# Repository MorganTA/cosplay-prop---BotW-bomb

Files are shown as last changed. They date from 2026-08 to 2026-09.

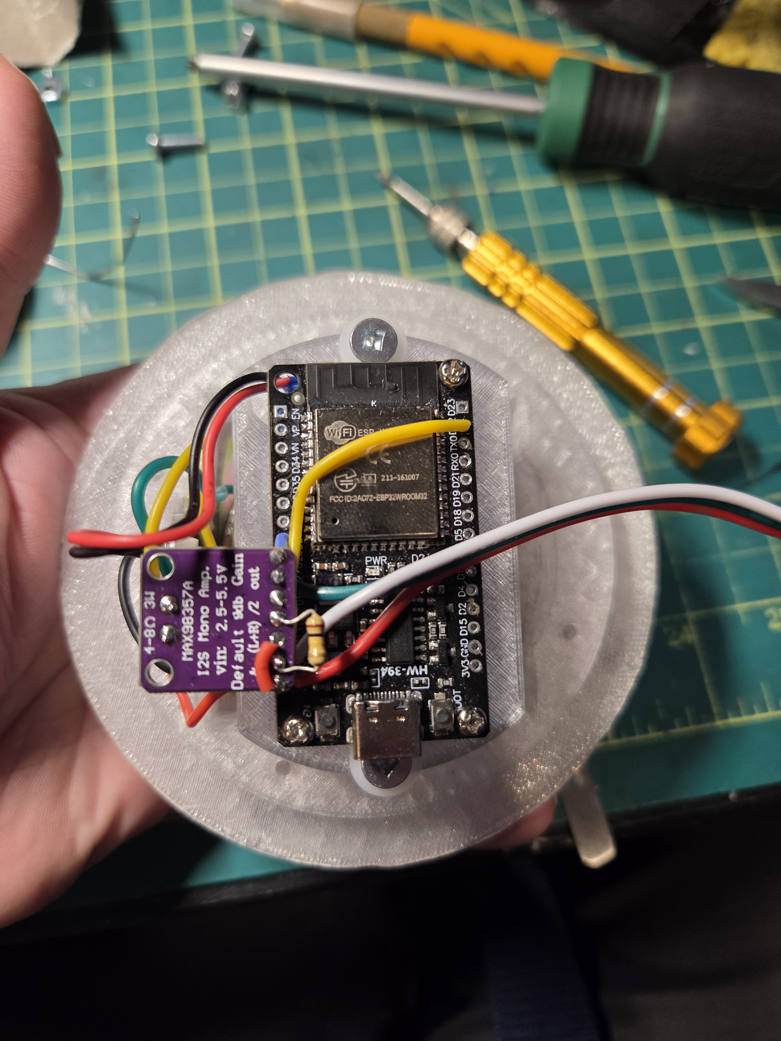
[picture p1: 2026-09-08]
Assembly Pictures/BoTW Remote Bomb Assembly (9).jpg

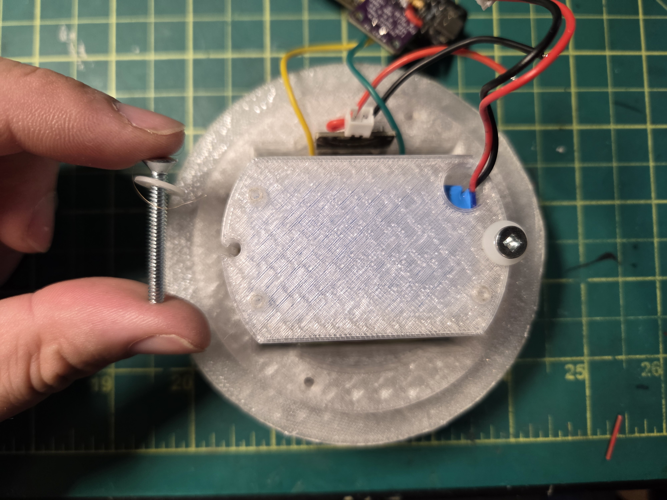
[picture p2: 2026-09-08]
Assembly Pictures/BoTW Remote Bomb Assembly (5).jpg

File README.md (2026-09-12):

# Zelda: Breath of the Wild — Remote Bomb Prop
https://www.instagram.com/reel/DdAoqvsIL6p/?stkn=bnQzZnl1bjlta2x1

Here is the codes for my Breath of the Wild Remote Bomb prop. I have a phone in my Sheikah slate, so I wanted to connect the bomb with Bluetooth to control it.
I had to upload the HTML file to make the APK, so I might as well share it here for anyone who wants to try and make one.

The project was coded with Claude AI, so feel free to modify it as you want. You might want to change the LED count, its currently set for 36 from when I was doing the initial tests.
I also used it for most of this documentation because I am not going to be putting a lot of effort into this.

---
## 3D Model

This is the original model I used.
https://www.thingiverse.com/thing:4860007

I modified it fit a 6-inch Mr.Go LED ball. I'm not vert good with modeling, I used 3D builder to modify the model. Hopefully you wont have much trouble using them. I'll add my WIP file if it helps anyone with editing, please not that it's not that great, and some parts might not fit as the finished ones do.

---

## Features

- Bluetooth Low Energy control via a web app (no app install required on Android)
- Blue breathing LED glow when armed
- Red fade-to-off LED explosion effect on detonation
- I2S audio playback through a MAX98357A amplifier
- Volume slider in the control app
- Works fully offline after first load (PWA with service worker caching)
- Can be installed as a standalone Android app (no address bar) via PWABuilder

---

## Hardware

| Part | Notes | Link |
|---|---|---|
| Mr.Go 6-inch RGB Color-Changing LED Ball Light | I used this for the main body | https://www.amazon.ca/dp/B01HXXUZFG?ref=ppx_yo2ov_dt_b_fed_asin_title&th=1 |
| ESP-WROOM-32 dev board | Any standard ESP32 Dev Module works |
| MAX98357A I2S amp | Digital amp + DAC in one chip, no separate DAC needed | https://www.aliexpress.com/item/1005008274847319.html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 |
| Speaker | 4Ω or 8Ω, 3W | I had mine laying around. Its about 53mmx53mmx24mm |
| WS2812B addressable LEDs | Strip or ring, 36 LEDs | |
| LiPo battery | 3.7V | I just took the one from the Mr.Go light |
| Battery Charging & Boost Converter | I had some of these left over and it saves on space not needing two boards | https://www.aliexpress.com/item/1005005108273423.html?spm=a2g0o.order_list.order_list_main.82.6e0f1802KXwK5v |
| SPDT 1P2T toggle switch | 8.5mm x 3.5mm handle 3mm | https://www.aliexpress.com/item/1005010111050912.html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 |
| 100kΩ resistor | for the MAX98357A audio chip to increase volume | |
| 330Ω resistor | In series on the WS2812B data line |  |
| 470–1000µF capacitor | Across the 5V/GND rail near the LED strip |  |

---

## Wiring

### MAX98357A → ESP32

| MAX98357A | ESP32 |
|---|---|
| VIN | 5V |
| GND | GND |
| BCLK | GPIO26 |
| LRC (WS) | GPIO25 |
| DIN | GPIO22 |
| GAIN | GND (12dB), or 100kΩ resistor to GND (15dB max) |
| SD | VIN (always enabled) |

Connect the speaker's two leads to the MAX98357A's `+` and `−` output terminals.

### WS2812B LEDs → ESP32

| LED | ESP32 |
|---|---|
| VCC | 5V |
| GND | GND |
| DIN | GPIO27 (through a 330Ω resistor) |

### Power rail

```
LiPo (+) → TP4056 IN+ → TP4056 OUT+ → Boost converter IN+
→ Boost converter OUT+ (5V) → [SWITCH] → ESP32 5V / MAX98357A VIN / LED VCC
```

All GND connections share a common rail. Place a 470–1000µF capacitor across 5V/GND near the LED strip to prevent brownouts during bright flashes.

> **Tip:** Wire the switch after the boost converter, not before the TP4056. This way the battery charges normally via USB even when the prop is switched off.

---

## Firmware

### Prerequisites

- [Arduino IDE 2.x](https://www.arduino.cc/en/software)
- ESP32 board package by Espressif Systems **3.0 or later** (add `https://raw.githubusercontent.com/espressif/arduino-esp32/gh-pages/package_esp32_index.json` to Additional Board Manager URLs)
- [arduino-littlefs-upload](https://github.com/earlephilhower/arduino-littlefs-upload) plugin for Arduino IDE 2.x

### Libraries (install via Library Manager)

- **NimBLE-Arduino** by h2zero
- **Adafruit NeoPixel** by Adafruit

> The I2S driver and LittleFS are both bundled with the ESP32 board package — no extra install needed.

### Board settings

| Setting | Value |
|---|---|
| Board | ESP32 Dev Module |
| Partition Scheme | Huge APP (3MB No OTA/1MB SPIFFS) |
| PSRAM | Disabled |

### Audio files

Prepare two files:
- `Bomb_appear01.wav` — played when the bomb is armed
- `RemoteBomb.wav` — played on detonation (~2 seconds)

Both must be **16-bit PCM WAV** format. Mono or stereo both work. 22050 Hz or 44100 Hz sample rate recommended. You can convert and export in this format using [Audacity](https://www.audacityteam.org/) (File > Export > Export as WAV > Encoding: 16-bit PCM).

Place both files in a folder named `data` inside the sketch folder:

```
botw_bomb_firmware/
├── botw_bomb_firmware.ino
└── data/
    ├── Bomb_appear01.wav
    └── RemoteBomb.wav
```

### Flashing

**Step 1 — Upload the audio files (do this first)**

1. Close the Serial Monitor if it's open (the port must be free)
2. Select the correct board and COM port under Tools
3. Open the Command Palette (`Ctrl+Shift+P` / `Cmd+Shift+P`) and run **Upload LittleFS to Pico/ESP32**
4. Wait for it to finish before continuing

**Step 2 — Upload the sketch**

1. Click the **Upload** button as normal
2. Open Serial Monitor at **115200 baud**
3. Confirm you see: `Advertising as 'BotW Bomb' — open the web app and tap Connect.`

> If you change the partition scheme at any point, re-upload the LittleFS filesystem too — changing the partition layout moves where the filesystem lives in flash.

---

## Control App

The web app (`bomb_detonator.html`) is a Progressive Web App that runs in Chrome on Android. It communicates with the ESP32 over Web Bluetooth.

You can run the detonator program right from your web browser (Chrome is recommended) or you can download the apk from this repository. (the apk just loads the site)
https://morganta.github.io/cosplay-prop---BotW-bomb/bomb_detonator.html

If you want to host it yourself follow the info down below. If your just running it as is you don't need to worry, but if you want to make changes of your own you'll need to do it.

### Hosting

Web Bluetooth requires a secure origin (HTTPS or localhost). Host the app files on any free static host:

- [GitHub Pages](https://pages.github.com) (free, recommended)
- [Netlify Drop](https://app.netlify.com/drop) (no account needed, drag and drop)

Upload all five files together:

```
bomb_detonator.html
manifest.json
sw.js
icon-192.png
icon-512.png
```

### Offline use

The service worker (`sw.js`) caches everything after the first successful load over a network connection. Once cached, the app works fully offline. Open it once while connected to WiFi to prime the cache.

> Whenever you update the app files, bump the `CACHE_NAME` version string in `sw.js` (e.g. `v4` → `v5`) so the service worker fetches and re-caches the updated files next time it's online.

### Installing as a standalone Android app (no address bar)

Use [PWABuilder](https://www.pwabuilder.com) to generate a signed APK:

1. Enter your hosted HTTPS URL and click **Start**
2. Choose **Android** as the package type
3. Set your app name and choose **Create new** for the signing key — save the keystore file and credentials somewhere safe
4. Download the generated ZIP and copy the `.apk` file to your phone via USB
5. Upload the included `assetlinks.json` to your hosted site at `/.well-known/assetlinks.json` — this proves domain ownership so the app can go truly fullscreen
6. Install the APK on your phone (Settings > Apps > allow installs from your file manager if prompted)
7. Open the app once while online to let the service worker cache everything

### Usage

1. Open the app and tap **Connect Bomb** — select **BotW Bomb** from the device picker
2. Tap the bomb icon once to arm (blue glow + appear sound)
3. Tap again to detonate (red flash + explosion sound)
4. Use the volume slider to adjust playback volume

---

## Customisation

| Thing to change | Where |
|---|---|
| Number of LEDs | `#define NUM_LEDS` in the firmware |
| LED data pin | `#define LED_PIN` in the firmware |
| I2S pins | `#define I2S_BCLK / I2S_LRC / I2S_DOUT` in the firmware |
| Explosion duration | `#define BOOM_MIN_DURATION_MS` in the firmware |
| Audio filenames | `playWav()` calls in `handleTrigger()` |
| BLE device name | `NimBLEDevice::init()` and `scanResponseData.setName()` in setup |

---

## Troubleshooting

| Problem | Fix |
|---|---|
| `Could not open COM port` | Close the Serial Monitor before uploading |
| `Sketch too big` | Set Partition Scheme to **Huge APP (3MB No OTA/1MB SPIFFS)** |
| `OOM: failed to allocate AudioBuffer` | Make sure PSRAM is set to **Disabled** in board settings |
| `override` compile errors | Update the ESP32 board package to 3.x |
| No audio, no error | Check SD pin is wired to VIN on the MAX98357A; verify BCLK/LRC/DIN wiring |
| BLE shows as Unknown Device | Re-flash after confirming `scanResponseData.setName()` is in setup |
| App icon not going red | Hard-refresh Chrome after updating the hosted files |
| APK won't install | Try transferring via USB cable; check for a Play Protect warning to dismiss |
| App needs internet to launch | Open it once while on WiFi to let the service worker cache everything |

---

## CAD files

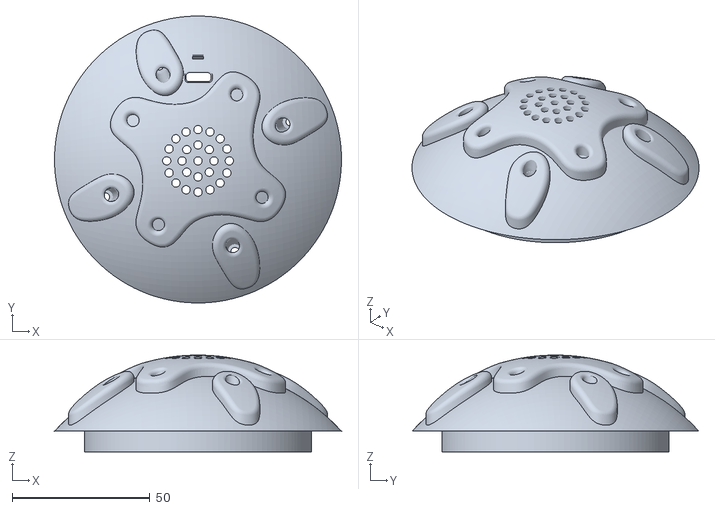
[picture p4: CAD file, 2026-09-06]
3D Model/RemoteBomb_Bottom.stl
104.1 x 104.0 x 35.1

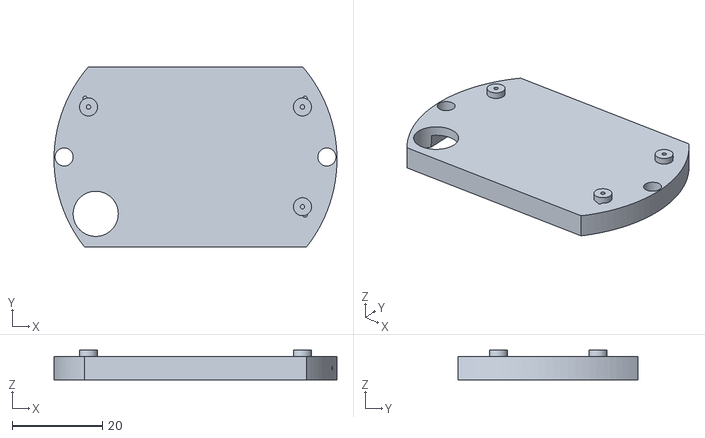
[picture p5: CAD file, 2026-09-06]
3D Model/ESP holder.stl
62.8 x 40.0 x 6.57

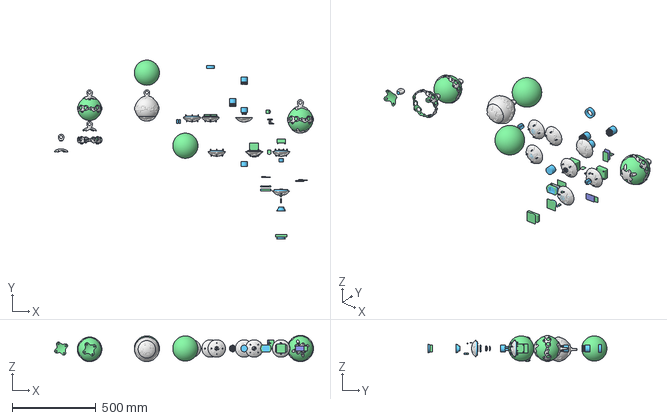
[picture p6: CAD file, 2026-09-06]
3D Model/Remote bomb WIP.3mf
1542.9 x 1065.4 x 156.0 mm

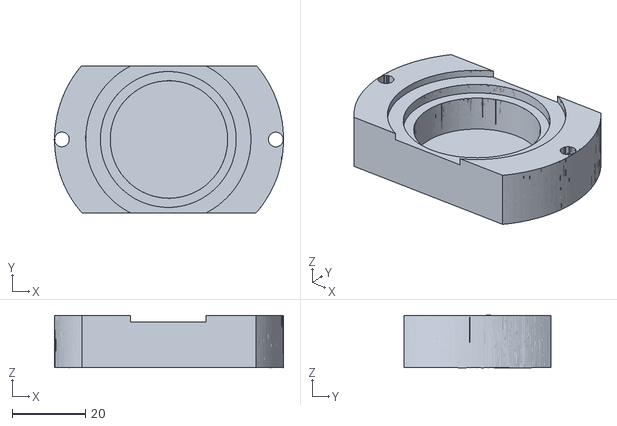
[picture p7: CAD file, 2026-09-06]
3D Model/Battery_holder.stl
62.4 x 40.0 x 14.3

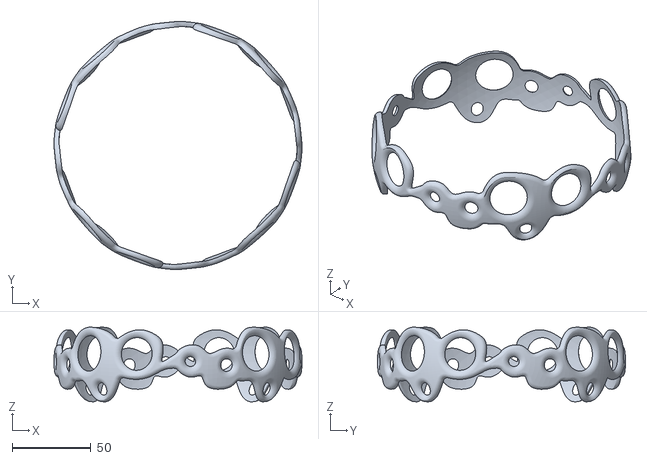
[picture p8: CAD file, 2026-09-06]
3D Model/RemoteBomb_Outer_Rings.stl
157.0 x 157.0 x 47.3

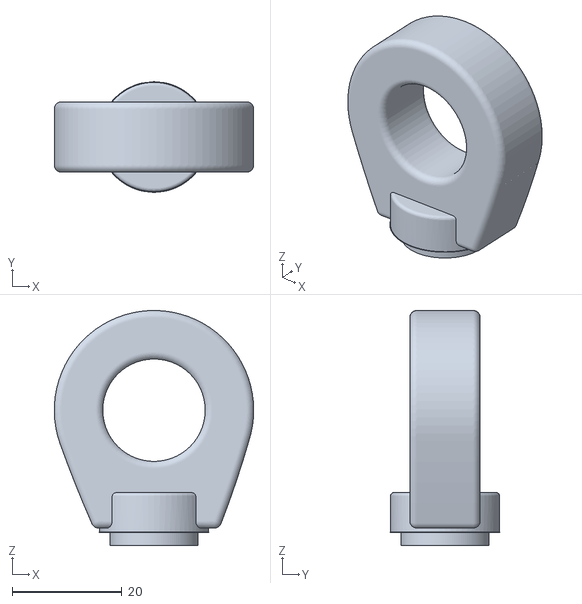
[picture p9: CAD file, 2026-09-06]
3D Model/RemoteBomb_Top_handel.stl
36.3 x 20.1 x 42.7

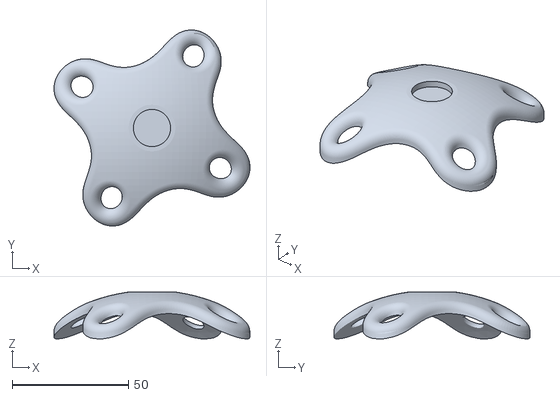
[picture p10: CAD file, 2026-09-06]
3D Model/RemoteBomb_Top.stl
84.4 x 84.4 x 20.2

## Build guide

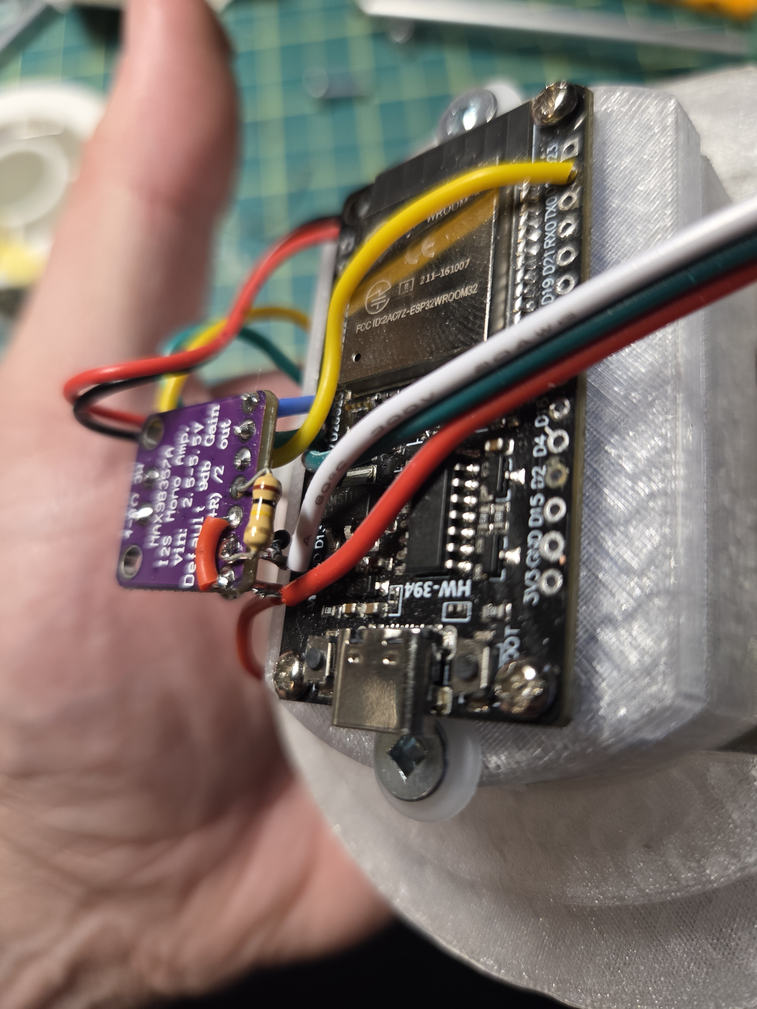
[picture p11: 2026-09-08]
Assembly Pictures/BoTW Remote Bomb Assembly (8).jpg

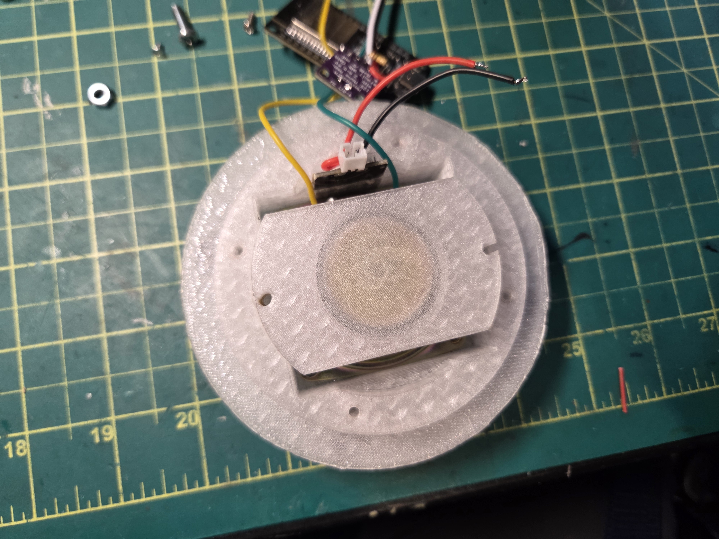
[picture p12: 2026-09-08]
Assembly Pictures/BoTW Remote Bomb Assembly (4).jpg

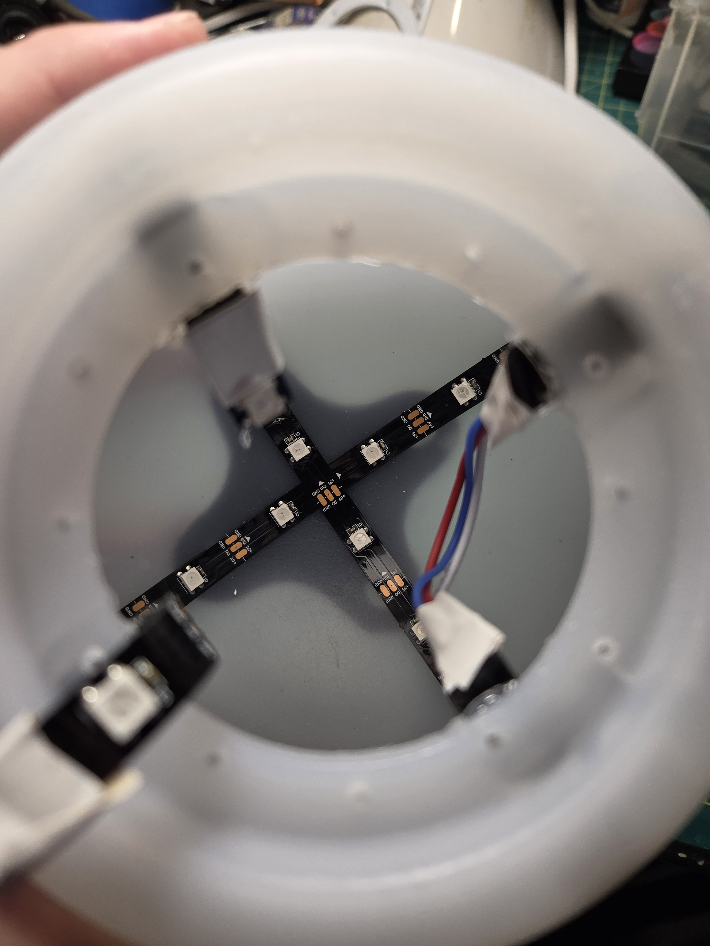
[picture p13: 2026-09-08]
Assembly Pictures/BoTW Remote Bomb Assembly (10).jpg

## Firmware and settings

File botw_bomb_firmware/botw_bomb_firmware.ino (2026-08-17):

/*
 * Zelda BotW Remote Bomb Prop — ESP32 firmware
 * ESP-WROOM-32 + MAX98357A (I2S amp) + WS2812B LEDs, controlled over BLE
 *
 * Behavior:
 *   Idle          -> LEDs fully off, no sound
 *   1st trigger   -> plays "Bomb_appear01.wav", LEDs soft breathing blue glow
 *   2nd trigger   -> plays "RemoteBomb.wav" (~2s), LEDs flash red for at least
 *                    that long, then LEDs go back off and it's ready to arm again
 *
 * This version plays WAV files directly through the ESP32's built-in I2S
 * driver instead of using the ESP32-audioI2S library. That library is built
 * for streaming/decoding (mp3, internet radio, etc.) and its buffer sizes
 * assume a board with PSRAM; on a plain non-PSRAM ESP-WROOM-32 it can fail
 * to allocate its audio buffer. Since we only need to play two short local
 * WAV clips, a small hand-rolled player avoids that dependency completely
 * and uses only a couple KB of RAM.
 *
 * Libraries required (install via Arduino Library Manager):
 *   - NimBLE-Arduino          by h2zero
 *   - Adafruit NeoPixel       by Adafruit
 *   (LittleFS and the I2S driver both come bundled with the ESP32 board package)
 *
 * Audio files:
 *   Put your own "Bomb_appear01.wav" and "RemoteBomb.wav" (16-bit PCM WAV,
 *   mono or stereo, any standard sample rate) in this sketch's /data folder,
 *   then upload with the LittleFS/SPIFFS uploader tool.
 *
 * Board settings: any standard ESP32 dev module board definition works.
 */

#include <NimBLEDevice.h>
#include <Adafruit_NeoPixel.h>
#include <LittleFS.h>
#include <driver/i2s.h>

// Defined up here (before any function that uses it) so Arduino's
// auto-generated function prototypes - which it inserts near the top of the
// file - can see this type instead of erroring on an unknown type.
struct WavInfo {
  uint32_t sampleRate = 44100;
  uint16_t bitsPerSample = 16;
  uint16_t numChannels = 1;
  uint32_t dataSize = 0;
};

// ---------- Pin map ----------
#define LED_PIN      27
#define NUM_LEDS     36

#define I2S_BCLK     26
#define I2S_LRC      25
#define I2S_DOUT     22
#define I2S_PORT     I2S_NUM_0

// ---------- BLE UUIDs (must match the web app) ----------
#define SERVICE_UUID        "4fafc201-1fb5-459e-8fcc-c5c9c331914b"
#define CHARACTERISTIC_UUID "beb5483e-36e1-4688-b7f5-ea07361b26a8"

// Minimum time (ms) the red flash stays active, so it always covers the
// ~2 second explosion clip even if the file is a little shorter/longer.
#define BOOM_MIN_DURATION_MS 2200

Adafruit_NeoPixel strip(NUM_LEDS, LED_PIN, NEO_GRB + NEO_KHZ800);

NimBLEServer* pServer = nullptr;
NimBLECharacteristic* pChar = nullptr;
bool deviceConnected = false;

enum BombState { IDLE, ARMED, BOOM };
BombState state = IDLE;
unsigned long stateStart = 0;

volatile float g_volume = 0.8f; // 0.0-1.0, controlled by the app's slider

// Forward declarations (needed because these are called from classes defined
// below, before Arduino's auto-prototype generator has a chance to see them)
void notifyState(const char* s);
void handleTrigger();

// ---------- BLE callbacks ----------
class ServerCallbacks : public NimBLEServerCallbacks {
  void onConnect(NimBLEServer* s, NimBLEConnInfo& connInfo) override {
    deviceConnected = true;
    Serial.println("Phone connected");
  }
  void onDisconnect(NimBLEServer* s, NimBLEConnInfo& connInfo, int reason) override {
    deviceConnected = false;
    Serial.println("Phone disconnected, re-advertising");
    NimBLEDevice::startAdvertising();
  }
};

class TriggerCallback : public NimBLECharacteristicCallbacks {
  void onWrite(NimBLECharacteristic* c, NimBLEConnInfo& connInfo) override {
    std::string v = std::string(c->getValue().c_str());
    if (v.empty()) return;

    if (v[0] == 'T') {
      handleTrigger();
    } else if (v[0] == 'V' && v.size() >= 3 && v[1] == ':') {
      // Volume command, format "V:<0-100>" (percent)
      int pct = atoi(v.substr(2).c_str());
      pct = constrain(pct, 0, 100);
      g_volume = pct / 100.0f;
      Serial.printf("Volume set to %d%%\n", pct);
    }
  }
};

void notifyState(const char* s) {
  if (pChar && deviceConnected) {
    pChar->setValue(s);
    pChar->notify();
  }
}

// ---------- LED effects ----------
void setAll(uint32_t c) {
  for (int i = 0; i < NUM_LEDS; i++) strip.setPixelColor(i, c);
  strip.show();
}

void idleEffect() {
  setAll(strip.Color(0, 0, 0)); // fully off
}

void armedEffect() {
  // gentle, constant breathing blue glow
  const float periodMs = 1800.0;
  float phase = fmod((float)millis(), periodMs) / periodMs;
  float b = (sin(phase * 2 * PI) + 1) / 2.0; // 0..1
  int brightness = 20 + (int)(b * 180);      // 20..200
  setAll(strip.Color(0, brightness / 3, brightness)); // soft cyan-blue
}

void boomEffect() {
  unsigned long elapsed = millis() - stateStart;

  if (elapsed < BOOM_MIN_DURATION_MS) {
    // bright red immediately, then eases down to off over the rest of the duration
    float t = (float)elapsed / (float)BOOM_MIN_DURATION_MS; // 0..1
    float decay = 1.0f - (t * t);                           // eased falloff, stays brighter longer up front
    int brightness = (int)(255 * decay);
    if (brightness < 0) brightness = 0;
    setAll(strip.Color(brightness, 0, 0));
  } else {
    setAll(strip.Color(0, 0, 0));
  }
}

// ---------- WAV playback (built-in I2S driver, no external audio library) ----------
bool parseWav(File &f, WavInfo &info) {
  f.seek(0);
  char tag[4];
  uint32_t skip32;

  if (f.read((uint8_t*)tag, 4) != 4 || memcmp(tag, "RIFF", 4) != 0) return false;
  f.read((uint8_t*)&skip32, 4); // RIFF chunk size, unused
  if (f.read((uint8_t*)tag, 4) != 4 || memcmp(tag, "WAVE", 4) != 0) return false;

  while (f.available()) {
    char id[4];
    uint32_t size;
    if (f.read((uint8_t*)id, 4) != 4) break;
    if (f.read((uint8_t*)&size, 4) != 4) break;

    if (memcmp(id, "fmt ", 4) == 0) {
      uint16_t audioFormat, numChannels, blockAlign, bitsPerSample;
      uint32_t sampleRate, byteRate;
      f.read((uint8_t*)&audioFormat, 2);
      f.read((uint8_t*)&numChannels, 2);
      f.read((uint8_t*)&sampleRate, 4);
      f.read((uint8_t*)&byteRate, 4);
      f.read((uint8_t*)&blockAlign, 2);
      f.read((uint8_t*)&bitsPerSample, 2);
      info.numChannels = numChannels;
      info.sampleRate = sampleRate;
      info.bitsPerSample = bitsPerSample;
      if (size > 16) f.seek(size - 16, SeekCur); // skip any extra fmt bytes
    } else if (memcmp(id, "data", 4) == 0) {
      info.dataSize = size;
      return true; // data chunk found and file cursor is positioned right after its header
    } else {
      f.seek(size, SeekCur); // skip chunk we don't care about (e.g. LIST, INFO)
    }
    if (size % 2 == 1) f.seek(1, SeekCur); // chunks are word-aligned
  }
  return false;
}

static uint8_t s_readBuf[1024];
static uint8_t s_writeBuf[2048];

bool playWav(const char* path) {
  File f = LittleFS.open(path, "r");
  if (!f) {
    Serial.printf("Could not open %s\n", path);
    return false;
  }

  WavInfo info;
  if (!parseWav(f, info) || info.bitsPerSample != 16) {
    Serial.printf("Unsupported/invalid WAV: %s (need 16-bit PCM)\n", path);
    f.close();
    return false;
  }

  i2s_set_clk(I2S_PORT, info.sampleRate, I2S_BITS_PER_SAMPLE_16BIT, I2S_CHANNEL_STEREO);

  uint32_t remaining = info.dataSize;
  while (remaining > 0) {
    size_t toRead = min((uint32_t)sizeof(s_readBuf), remaining);
    size_t got = f.read(s_readBuf, toRead);
    if (got == 0) break;
    remaining -= got;

    int16_t* samples = (int16_t*)s_readBuf;
    size_t numSamples = got / 2;

    // apply software volume with clipping
    for (size_t i = 0; i < numSamples; i++) {
      int32_t v = (int32_t)(samples[i] * g_volume);
      if (v > 32767) v = 32767;
      if (v < -32768) v = -32768;
      samples[i] = (int16_t)v;
    }

    size_t bytesWritten = 0;
    if (info.numChannels == 1) {
      // duplicate each mono sample into a stereo L+R frame
      int16_t* out = (int16_t*)s_writeBuf;
      for (size_t i = 0; i < numSamples; i++) {
        out[i * 2]     = samples[i];
        out[i * 2 + 1] = samples[i];
      }
      i2s_write(I2S_PORT, s_writeBuf, numSamples * 4, &bytesWritten, portMAX_DELAY);
    } else {
      i2s_write(I2S_PORT, s_readBuf, got, &bytesWritten, portMAX_DELAY);
    }
  }

  f.close();
  return true;
}

volatile bool triggerBusy = false;

void triggerTask(void* param) {
  if (state == IDLE) {
    state = ARMED;
    stateStart = millis();
    notifyState("ARMED");
    Serial.println("-> ARMED (blue glow)");
    playWav("/Bomb_appear01.wav"); // blocks this task briefly; LEDs keep animating via loop() independently
    // stays ARMED after the clip finishes - blue glow continues until the next press
  } else if (state == ARMED) {
    state = BOOM;
    stateStart = millis();
    notifyState("BOOM");
    Serial.println("-> BOOM (red flash)");
    playWav("/RemoteBomb.wav");
    // make sure the flash lasts at least BOOM_MIN_DURATION_MS even if the clip is shorter
    while (millis() - stateStart < BOOM_MIN_DURATION_MS) {
      vTaskDelay(pdMS_TO_TICKS(10));
    }
    state = IDLE;
    notifyState("IDLE");
    Serial.println("-> IDLE (off, ready to arm)");
  }
  triggerBusy = false;
  vTaskDelete(NULL);
}

void handleTrigger() {
  // Runs on the BLE host task - keep this fast and non-blocking. All the
  // actual playback/timing work happens in triggerTask on its own task, so
  // notify() calls go out immediately instead of getting stuck queued
  // behind several seconds of blocking audio playback.
  if (triggerBusy) return; // ignore taps while a sequence is already running
  triggerBusy = true;
  xTaskCreate(triggerTask, "triggerTask", 4096, nullptr, 1, nullptr);
}

// ---------- setup / loop ----------
void setup() {
  Serial.begin(115200);

  strip.begin();
  strip.show(); // starts fully off

  if (!LittleFS.begin(true)) {
    Serial.println("LittleFS mount failed — did you upload the /data folder?");
  }

  i2s_config_t i2sConfig = {
    .mode = (i2s_mode_t)(I2S_MODE_MASTER | I2S_MODE_TX),
    .sample_rate = 44100,
    .bits_per_sample = I2S_BITS_PER_SAMPLE_16BIT,
    .channel_format = I2S_CHANNEL_FMT_RIGHT_LEFT,
    .communication_format = I2S_COMM_FORMAT_STAND_I2S,
    .intr_alloc_flags = ESP_INTR_FLAG_LEVEL1,
    .dma_buf_count = 6,
    .dma_buf_len = 256,
    .use_apll = false,
    .tx_desc_auto_clear = true
  };
  i2s_driver_install(I2S_PORT, &i2sConfig, 0, NULL);

  i2s_pin_config_t pinConfig = {
    .bck_io_num = I2S_BCLK,
    .ws_io_num = I2S_LRC,
    .data_out_num = I2S_DOUT,
    .data_in_num = I2S_PIN_NO_CHANGE
  };
  i2s_set_pin(I2S_PORT, &pinConfig);

  NimBLEDevice::init("BotW Bomb");
  pServer = NimBLEDevice::createServer();
  pServer->setCallbacks(new ServerCallbacks());

  NimBLEService* pService = pServer->createService(SERVICE_UUID);
  pChar = pService->createCharacteristic(
      CHARACTERISTIC_UUID,
      NIMBLE_PROPERTY::WRITE | NIMBLE_PROPERTY::NOTIFY
  );
  pChar->setCallbacks(new TriggerCallback());
  pService->start();

  NimBLEAdvertising* pAdv = NimBLEDevice::getAdvertising();
  pAdv->addServiceUUID(SERVICE_UUID);
  pAdv->setName("BotW Bomb");     // NimBLE 2.x doesn't advertise the name by default anymore
  pAdv->enableScanResponse(true); // puts the name in the scan response so it fits alongside the service UUID
  pAdv->start();

  Serial.println("Advertising as 'BotW Bomb' — open the web app and tap Connect.");
}

void loop() {
  // handleTrigger() (called from the BLE task when a button press comes in)
  // blocks briefly while it plays audio - this loop keeps running independently
  // on its own task the whole time, so the LEDs stay animated based on 'state'.
  switch (state) {
    case IDLE:  idleEffect();  break;
    case ARMED: armedEffect(); break;
    case BOOM:  boomEffect();  break;
  }
}
